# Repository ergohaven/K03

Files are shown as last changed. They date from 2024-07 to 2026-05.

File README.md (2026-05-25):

## K:03 is an ergonomic, split, mechanical keyboard with five thumb keys on each half and the ability to install encoders on either half

*K:03 keeps a 60% footprint, a 60-key layout, and clean ergonomics across two versions: the Wired Edition and the Wireless Edition*

K:03 v4

## Design philosophy
K:03 combines futuristic styling, a compact form factor, and practical ergonomics. The Wired Edition is built for a feature-rich daily setup, and the Wireless Edition adds Bluetooth portability

K:03 v4 WE

## Features
- Split, ergonomic design
- 60 fully programmable keys and 15 additional layers for all your tasks
- Optional encoder support on either half
- Hot-swappable PCB (MX sockets)

### Wired Edition
- Powered by RP2040 and QMK firmware
- USB-C connection between halves
- Easily remap any key and customize your keyboard with [Vial](https://eh.industries/vial)
- OLED display and active-layer indicator

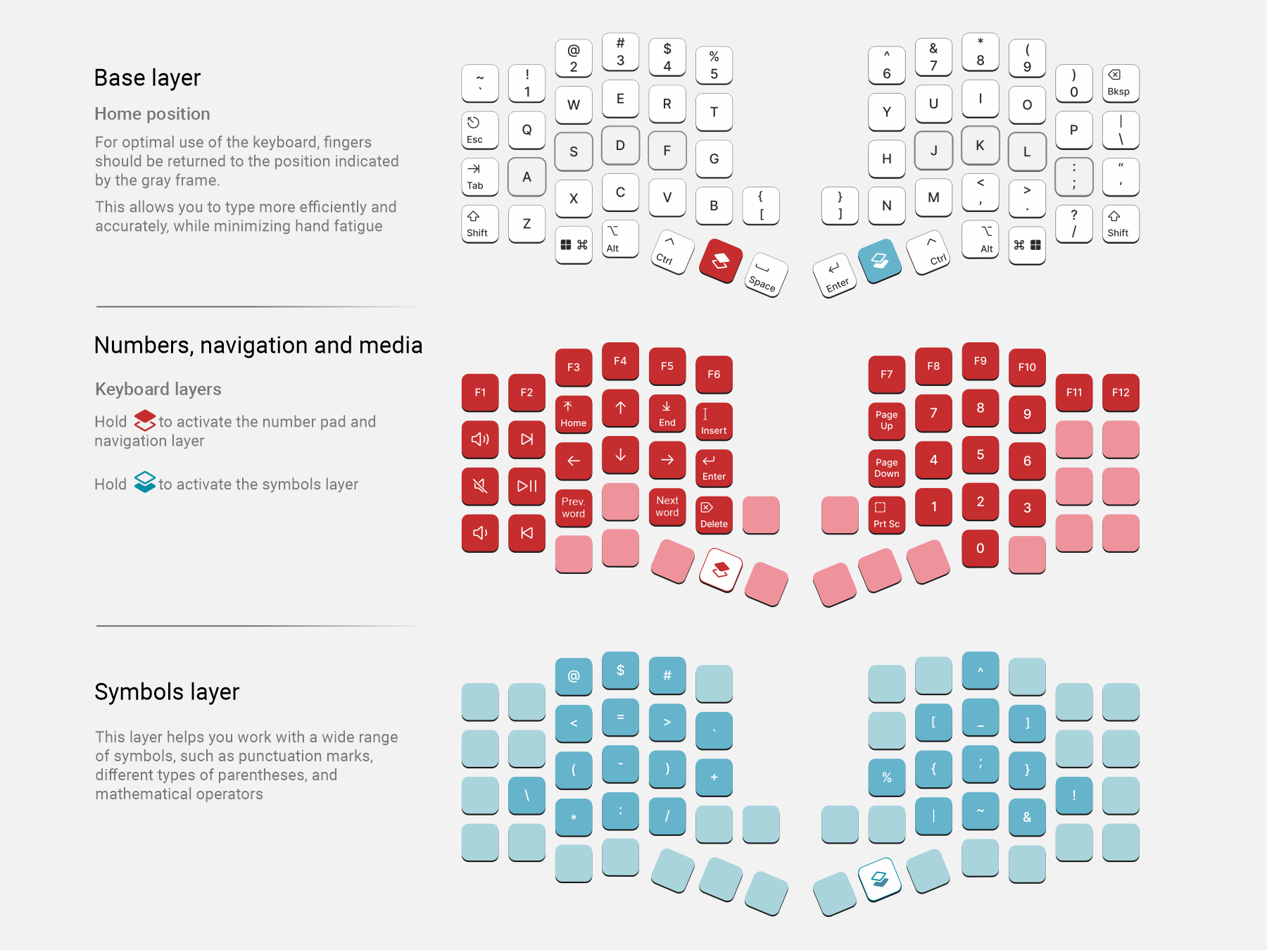
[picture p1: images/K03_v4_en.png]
K:03 v4 Layouts


### Wireless Edition
- Powered by nRF52840 and RMK/ZMK firmware
- Bluetooth connectivity for up to 6 devices
- Rechargeable 200 mAh battery
- USB-C connection

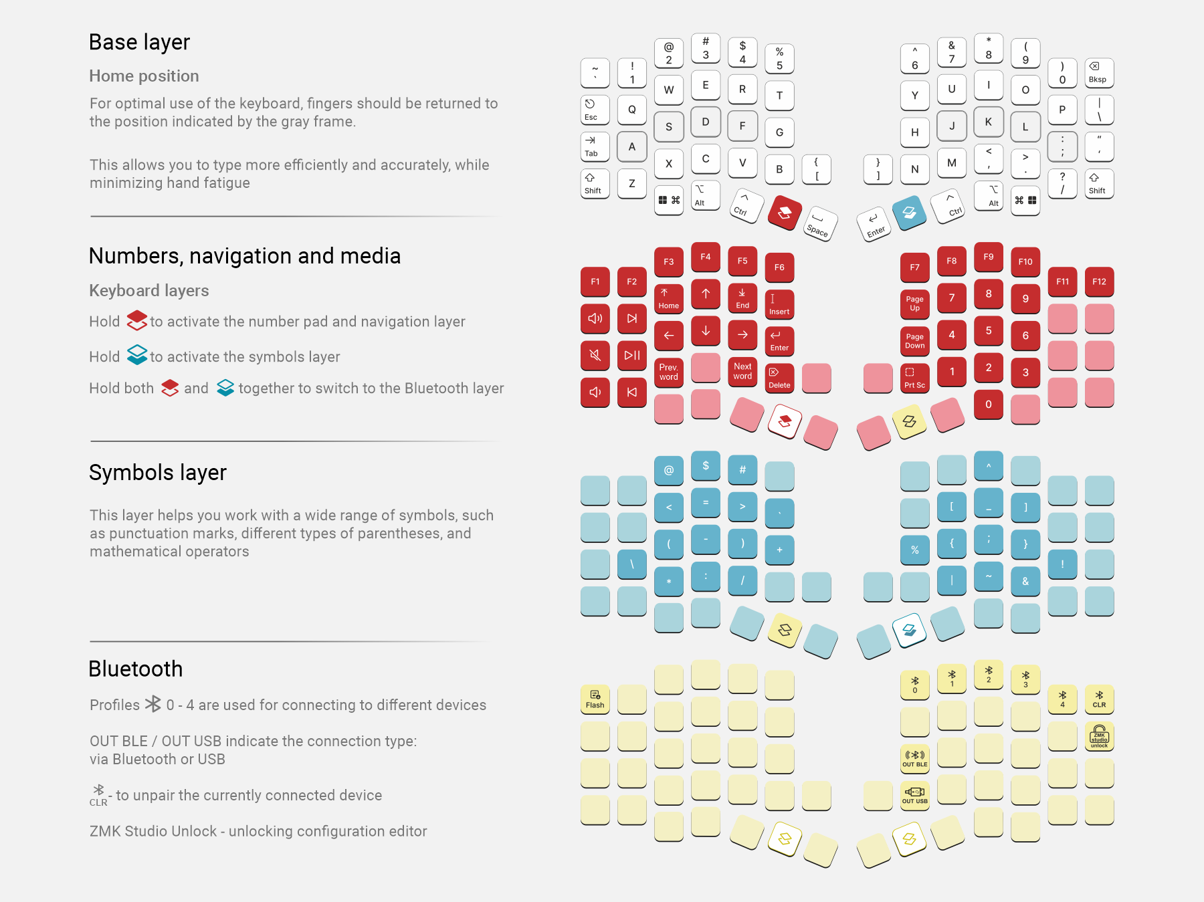
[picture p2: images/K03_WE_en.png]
K:03 v4 WE Layouts


## This repository contains all files related to this keyboard
PCB and schematic for [K:03 v4](https://oshwlab.com/yuriiq/project_vqxdarna) and [K:03 v4 – Wireless Edition](https://oshwlab.com/yuriiq/project_somqsptz)

### BOM
#### K:03 v4

| Components | Quantity (pcs) |
| --- | ---: |
| K:03 v4 PCB | 1 |
| RP2040 MCU, LQFN-56 | 2 |
| OLED SSD1306 Display, 128x32, DSP-OLED-128X32 | 2 |
| MX hotswap sockets | 60 |
| 1N4148W diodes, SOD-523F | 60 |
| Resistor 0402 5.1 kΩ | 8 |
| Resistor 0402 1 kΩ | 2 |
| Resistor 0402 200 Ω | 2 |
| Resistor 0402 27 Ω | 4 |
| Capacitor 0402 1 nF | 4 |
| Capacitor 0402 15 pF | 4 |
| Capacitor 0402 100 nF | 10 |
| Capacitor 0402 2.2 µF | 2 |
| SMD LED SK6803MINI-E-001 | 2 |
| P-channel MOSFET, SOT-23, JSM2301S | 2 |
| SMD tactile switch TS-1187F-1526 | 4 |
| LDO, SOT-23-3, 662K | 2 |
| SPI flash W25Q32JVSSIQ | 2 |
| SMD USB connector USB-TYPE-C-021 | 2 |
| SMD USB connector USB-TYPE-C-018 | 2 |
| SMD crystal resonator 12 MHz XXHCCLNANF-12.000000MHZ | 2 |
| 3M bumpons (8 mm) | 8 |
| MagSafe ring (optional) | 2 |

#### K:03 v4 – Wireless Edition

| Components | Quantity (pcs) |
| --- | ---: |
| K:03 Wireless Edition PCB | 1 |
| E73-2G4M08S1C Bluetooth module | 2 |
| MX hotswap sockets | 60 |
| 1N4148W diodes, SOD-523F | 60 |
| B5819WS Schottky diode, SOD-323 | 2 |
| Resistor 0402 5.1 kΩ | 6 |
| Resistor 0402 100 kΩ | 2 |
| Resistor 0402 806 kΩ | 2 |
| Resistor 0402 2 MΩ | 2 |
| Resistor 0402 10 kΩ | 2 |
| Capacitor 0402 4.7 µF | 4 |
| SMD LED SK6803MINI-E-001 | 2 |
| P-channel MOSFET, SOT-23, JSM2301S | 4 |
| MSK12CO2-SZ SMD slide switch | 2 |
| LN2054Y42AMR linear Li-Ion battery charger, SOT-23-5 | 2 |
| ZX-SH1.0-2PWT SMD wire-to-board connector | 2 |
| AP2112K-3.3TRG1 LDO regulator, SOT-23-5 | 2 |
| SMD USB connector USB-TYPE-C-018 | 2 |
| TS5235A 250gf 025 SMD tactile switch | 2 |
| Li-Pol, 3.7V, 200mAh, 402030 with JST SH-1.0mm, 2 pin connector | 2 |
| 3M bumpons (8 mm) | 8 |
| MagSafe ring (optional) | 2 |
| Plexiglass window for case, 24x23 mm (optional) | 2 |

## License
The files in this repository are licensed under the Creative Commons Attribution-NonCommercial-ShareAlike 4.0 International License

## Useful links

- K:03 v4:
  - [Case for 3D printing (STL)](stls/k03-v4)
  - [Case model for editing (STEP)](step/k03-v4)
  - [Circuit schematic](https://oshwlab.com/yuriiq/project_vqxdarna)

- K:03 v4 – Wireless Edition:
  - [Case for 3D printing (STL)](stls/k03-v4-we)
  - [Case model for editing (STEP)](step/k03-v4-we)
  - [Circuit schematic](https://oshwlab.com/yuriiq/project_somqsptz)

### Firmware
- [Pre-compiled files](https://github.com/ergohaven/keymap_hub)
- Source code:
  - wired [QMK](https://github.com/ergohaven/vial-qmk)
  - wireless [RMK](https://github.com/ergohaven/rmk-eh)

## Availability
The complete keyboard (not a DIY kit) is available for purchase at [eh.industries](https://eh.industries/)

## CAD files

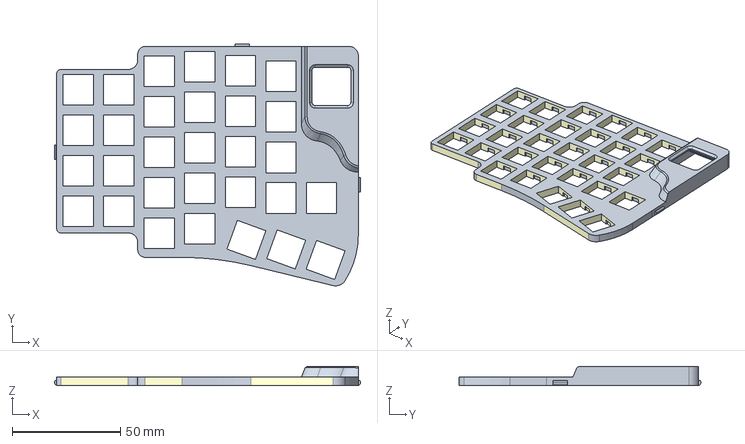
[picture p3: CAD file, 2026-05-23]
step/k03-v4-we/k3v4-we-top-left.stp
141.2 x 111.5 x 8.84 mm

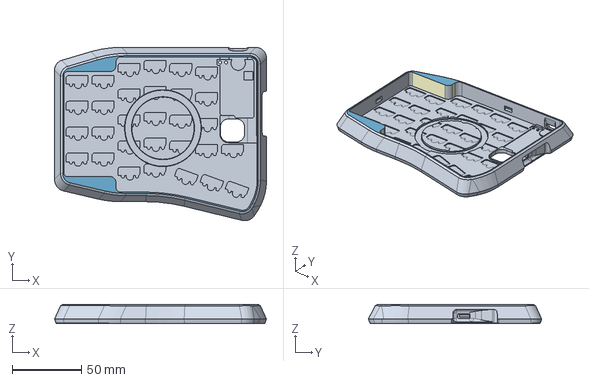
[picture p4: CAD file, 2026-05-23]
step/k03-v4/k3v4-body-left.stp
153.0 x 125.2 x 13.9 mm

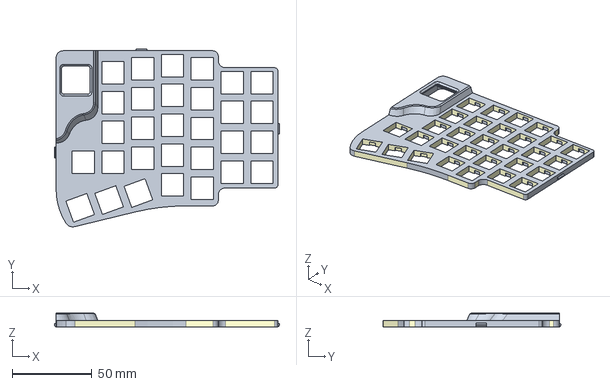
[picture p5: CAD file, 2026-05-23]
step/k03-v4-we/k3v4-we-top-right.stp
141.2 x 111.5 x 8.84 mm

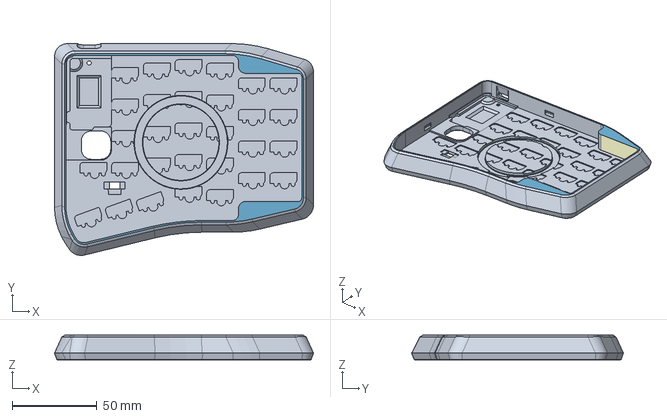
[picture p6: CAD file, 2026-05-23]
step/k03-v4-we/k3v4-we-body-right.stp
153.0 x 125.2 x 14.5 mm

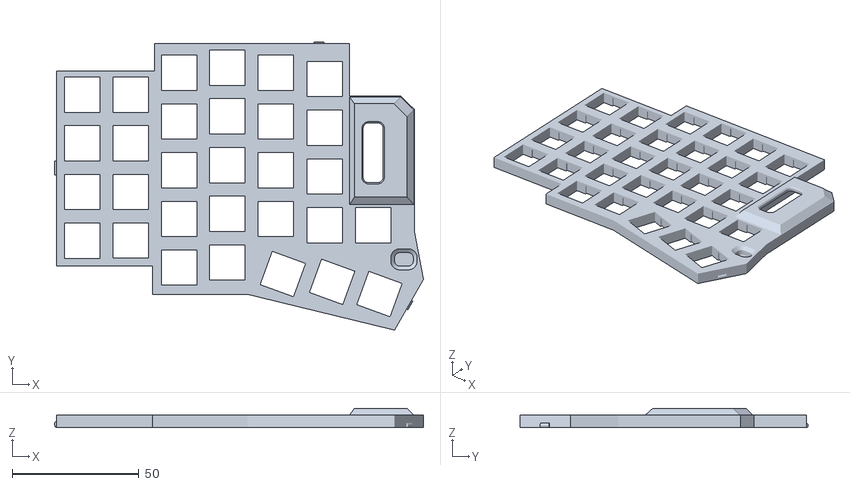
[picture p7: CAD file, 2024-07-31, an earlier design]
stls/k03-v1/k3v1-top-left.stl
145.6 x 113.8 x 7.66

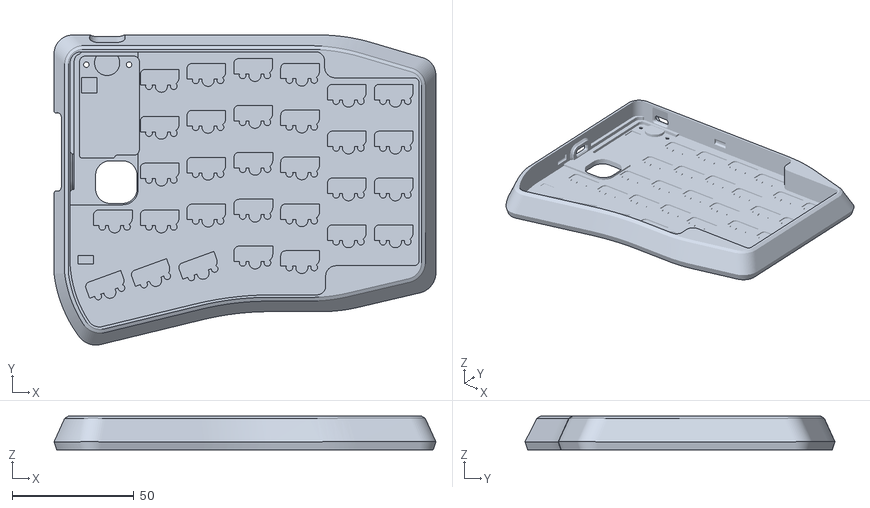
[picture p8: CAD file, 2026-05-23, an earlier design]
stls/k03-v3/k3v3-body-right.stl
156.8 x 127.3 x 13.9

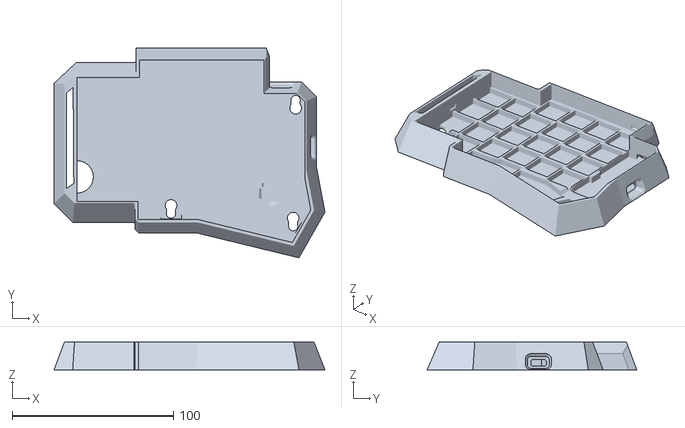
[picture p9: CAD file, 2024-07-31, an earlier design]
stls/k03-v1/k3v1-body.stl
168.1 x 130.0 x 17.2

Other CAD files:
stls/k03-v4-we/K3BT-body-left.stl
stls/k03-v4/k3v4-top-right-bl.stl
step/k03-v4-we/k3v4-we-left-right.stp
step/k03-v4/k3v4-top-left.stp
stls/k03-v4-we/K3BT-top-left.stl
stls/k03-v4/k3v4-top-left-bl.stl
step/k03-v4/k3v4-top-right.stp
stls/k03-v4-we/K3BT-top-right.stl
step/k03-v4/k3v4-body-right.stp
stls/k03-v4-we/K3BT-body-right.stl
stls/k03-v1/old thumbcluster/k3v1-top-left.stl
stls/k03-v1/k3v1-top-left-enc.stl
stls/k03-v1/k3v1-top-right-enc.stl
stls/k03-v1/k3v1-top-right.stl
stls/k03-v1/old thumbcluster/k3v1-top-left-enc.stl
stls/k03-v1/old thumbcluster/k3v1-top-right-enc.stl
stls/k03-v1/old thumbcluster/k3v1-top-right.stl
stls/k03-v3/k3v3-body-left.stl
stls/k03-v3/k3v3-top-left-bl.stl
stls/k03-v3/k3v3-top-left.stl
stls/k03-v3/k3v3-top-right-bl.stl
stls/k03-v3/k3v3-top-right.stl
stls/k03-v4/k3v4-body-left.stl
stls/k03-v4/k3v4-body-right.stl
stls/k03-v4/k3v4-top-left.stl
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
